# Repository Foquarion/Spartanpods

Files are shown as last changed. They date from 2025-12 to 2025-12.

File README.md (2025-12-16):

# Spartanpods Logo PCB Variations
Use Version 2 as the production model

# Version Description:
  - Version 1 is the original wave text version
  - Version 2 is the SQUARE PCB version (USE THIS ONE)
  - Version 3 is an incomplete start for a Helmet ONLY version. I have not completed it (no circuit) but the PCB is there for you to use

# To Do For You (Max):
Confirm SWITCH positioning
  - If alternate switch used, be aware of "Through-Hole nubs" on most other SMD switches (holes will be visible from the other side)
    
Phototransistor position
  - I did not leave the phototransistor overhanging over the edge, so be aware plaving it down will ~always appear as night-light active mode (I did this to leave a clean edge)
      + Adjust position to overhang if not desired
   
Battery:
  - Currently using a CR2032 coin cell because I already had the circuit done
  - Could probably fit AA or AAAs on here instead (or even a 9v adapter and use that as built-in stand)

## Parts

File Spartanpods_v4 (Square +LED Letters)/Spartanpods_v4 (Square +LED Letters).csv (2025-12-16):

Reference | Qty | Value | MFG P/N | Description | Footprint | Datasheet
BT1 | 1 | CR2032 | BH-49A-5 | BATTERY HOLDER COIN 2032 SMD | !MyFootprints:CR2032-Holder | ~
D1 | 1 | GRN | XZDGK45WT-9 | LED GREEN CLR 2PLCC SMD BOT ENT | !MyFootprints:LED - MyPLCC2 (RoundMask_LED Side) | ~
D2,D3,D4,D5 | 4 | RED | XZM2CRK45WT-9 | LED RED CLR 2PLCC SMD BOTTOM ENT | !MyFootprints:LED - MyPLCC2 (RoundMask_LED Side) | ~
Pot1 | 1 | 50K? | TC33X-2-503E | TRIMMER 50K OHM 0.15W J LEAD TOP | Potentiometer_SMD:Potentiometer_Bourns_TC33X_Vertical | ~
Q2 | 1 | Phototransistor | PT12-21C/TR8 | SENSOR PHOTO 940NM SIDE VIEW SMD | !MyFootprints:PhotoTrans_PT12-21C_TR8 (Flipped) | ~
Q3 | 1 | BC847 | BC847B,215 | TRANS NPN 45V 0.1A TO-236AB | Package_TO_SOT_SMD:SOT-23 | http://www.infineon.com/dgdl/Infineon-BC847SERIES_BC848SERIES_BC849SERIES_BC850SERIES-DS-v01_01-en.pdf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
R1 | 1 | 10K? | ESR03EZPJ103 | RES 10K OHM 5% 1/4W 0603 | Capacitor_SMD:C_0603_1608Metric_Pad1.08x0.95mm_HandSolder | ~
R2,R3,R4,R5,R6 | 5 | 56? | RC0805JR-0756RL | RES 56 OHM 5% 1/8W 0805 | Capacitor_SMD:C_0805_2012Metric_Pad1.18x1.45mm_HandSolder | ~
SW1 | 1 | SW_DP3T | JS203011SCQN | SWITCH SLIDE DP3T 300MA 6V |  | ~

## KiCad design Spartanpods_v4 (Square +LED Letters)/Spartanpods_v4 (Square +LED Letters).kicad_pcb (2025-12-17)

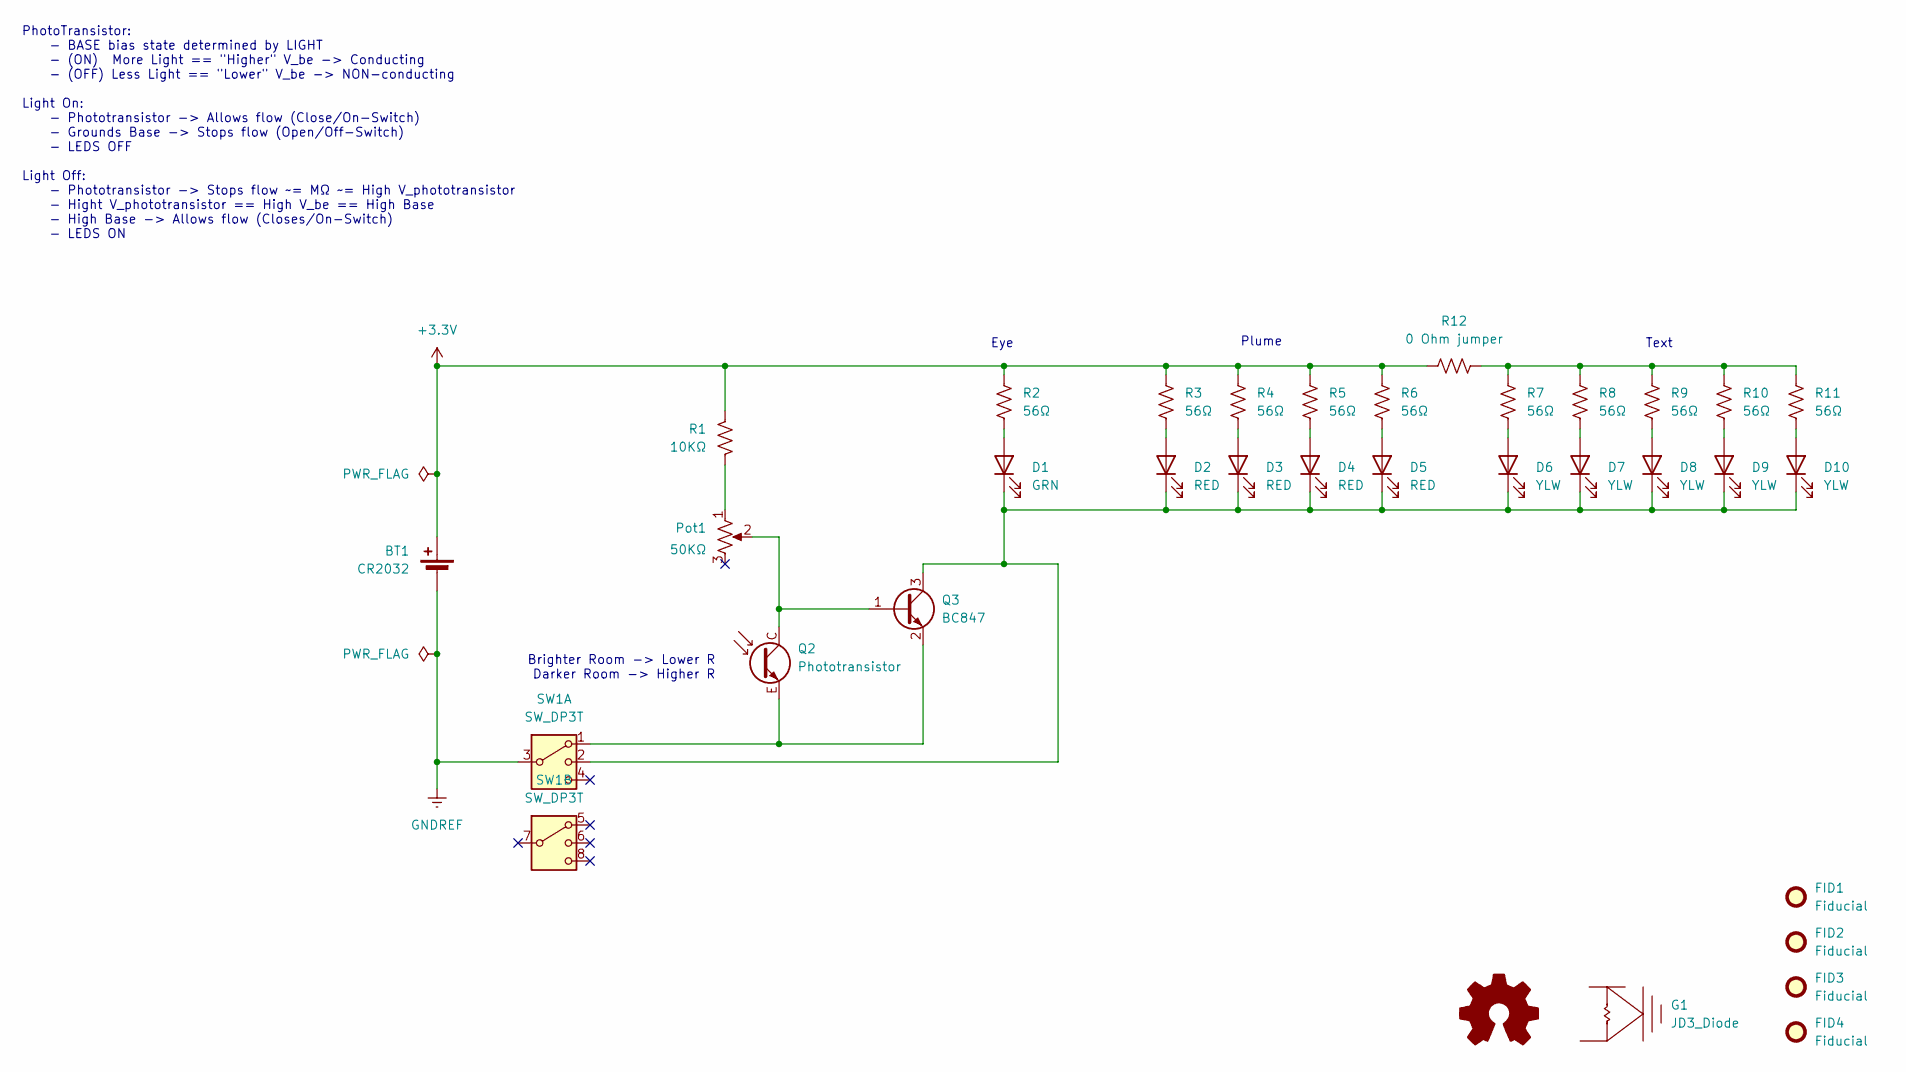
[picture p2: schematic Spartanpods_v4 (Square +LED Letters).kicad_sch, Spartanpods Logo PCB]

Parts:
BT1: CR2032; CR2032-Holder; MFG P/N BH-49A-5
D1: GRN; LED - MyPLCC2 (RoundMask_LED Side); MFG P/N XZDGK45WT-9
D2, D3, D4, D5: RED; LED - MyPLCC2 (RoundMask_LED Side); MFG P/N XZM2CRK45WT-9
D6, D7, D8, D9, D10: YLW; LED - MyPLCC2 (RoundMask_LED Side); MFG P/N XZM2CRK45WT-9
FID1, FID2, FID3, FID4: Fiducial; Fiducial_0.75mm_Mask2.25mm
G1: JD3_Diode
G2: Logo_Open_Hardware_Small; Combined_LED Text
Pot1: 50KΩ; Potentiometer_Bourns_TC33X_Vertical; MFG P/N TC33X-2-503E
Q2: Phototransistor; PhotoTrans_PT12-21C_TR8 (Flipped); MFG P/N PT12-21C/TR8
Q3: BC847; SOT-23; MFG P/N BC847B,215
R1: 10KΩ; C_0603_1608Metric_Pad1.08x0.95mm_HandSolder; MFG P/N ESR03EZPJ103
R2, R3, R4, R5, R6, R7, R8, R9, R10, R11: 56Ω; C_0805_2012Metric_Pad1.18x1.45mm_HandSolder; MFG P/N RC0805JR-0756RL
R12: 0 Ohm jumper; R_0805_2012Metric_Pad1.20x1.40mm_HandSolder
SW1: SW_DP3T; DP3T - JS203011SCQN; MFG P/N JS203011SCQN

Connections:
+3.3V: BT1.1 (Pos), R1.2, R2.1, R3.1, R4.1, R5.1, R6.1, R12.1
GNDREF: BT1.2 (Neg), SW1.3
unnamed: D1.2 (A), R2.2
unnamed: D1.1 (K), D2.1 (K), D3.1 (K), D4.1 (K), D5.1 (K), D6.1 (K), D7.1 (K), D8.1 (K), D9.1 (K), D10.1 (K), Q3.3 (C), SW1.2
unnamed: D2.2 (A), R3.2
unnamed: D3.2 (A), R4.2
unnamed: D4.2 (A), R5.2
unnamed: D5.2 (A), R6.2
unnamed: D6.2 (A), R7.2
unnamed: D7.2 (A), R8.2
unnamed: D8.2 (A), R9.2
unnamed: D9.2 (A), R10.2
unnamed: D10.2 (A), R11.2
unnamed: Pot1.1, R1.1
unnamed: Pot1.2, Q2.C (1), Q3.1 (B)
unnamed: Q2.E (2), Q3.2 (E), SW1.1
unnamed: R7.1, R8.1, R9.1, R10.1, R11.1, R12.2

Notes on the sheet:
Eye
Brighter Room -> Lower R Darker Room -> Higher R
Text
PhotoTransistor: - BASE bias state determined by LIGHT - (ON) More Light == "Higher" V_be -> Conducting - (OFF) Less Light == "Lower" V_be -> NON-conducting Light On: - Phototransistor -> Allows flow (Close/On-Switch) - Grounds Base -> Stops flow (Open/Off-Switch) - LEDS OFF Light Off: - Phototrans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
Plume

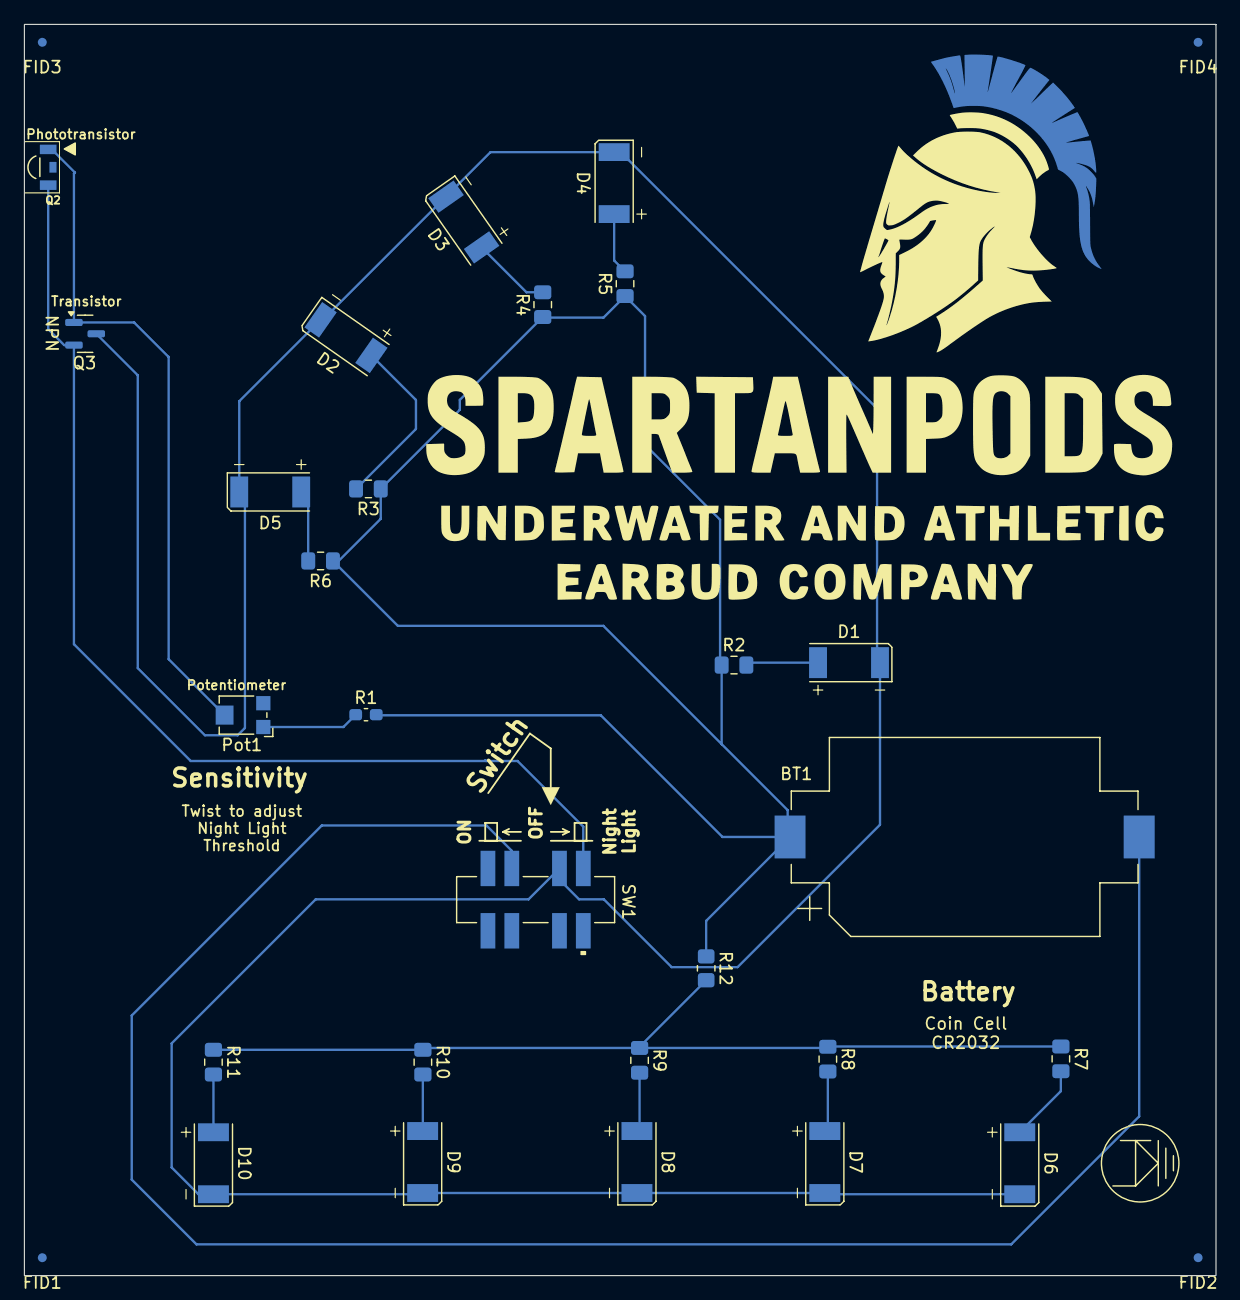
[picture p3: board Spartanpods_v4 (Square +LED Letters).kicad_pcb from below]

Board: 2 copper layers, 100.0 x 105.0 mm, 33 parts (32 on the bottom side), 17 nets.

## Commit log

2025-12-16 Included Library Package
    [Spartanpods_v2 (Square).kicad_pcb, Spartanpods_v2 (Square).kicad_sch]
2025-12-16 Add README for Spartanpods Logo PCB Variations
2025-12-16 Full Library Update
    [Spartanpods.kicad_sch]
2025-12-17 Spartanpods v4
    [Spartanpods_v4 (Square +LED Letters).csv, Spartanpods_v4 (Square +LED Letters).kicad_pcb, Spartanpods_v4 (Square +LED Letters).kicad_sch]
